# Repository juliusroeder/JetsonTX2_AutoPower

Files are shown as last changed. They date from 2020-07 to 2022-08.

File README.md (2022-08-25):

# JetsonTX2_AutoPower
Auto power on for the JetsonTX2 revision C02

One problem of the C02 revision of the Jetson TX2 dev kit is that auto power on is not easy to activate.
It includes desoldering and soldering 0402 resistors. The full process is described here: https://forums.developer.nvidia.com/t/auto-power-on-with-c02-carrier-board/70858

I needed a simpler way of automating the auto power on without the risk of damaging the TX2 by desoldering all other resistors next to R313.
Initially I tested the solution posted here: https://medium.com/@dumiloghin/auto-power-on-for-jetson-tx1-tx2-with-arduino-a5bd1b37659e
It turns on the TX2 using an Arduino Uno and is an excellent easy solution.

However, I needed a smaller form factor that could be co-hosted with the TX2 in a small steel enclosure.

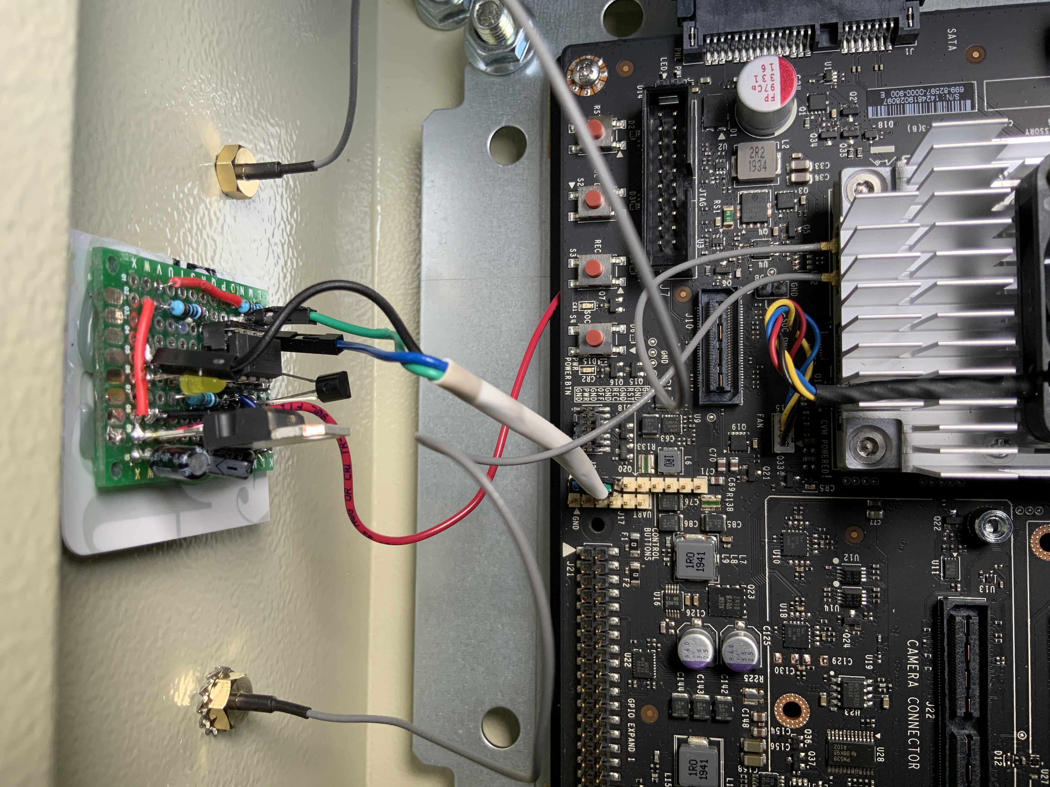
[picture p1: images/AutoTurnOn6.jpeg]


Additionally, the only power source available to drive any logic was the 20V rail on the TX2.
In this project I am using an LDO to regulate the 20V to 5V, power an ATtiny85 microcontroller and use it to turn on the TX2 via the J20 header. The microcontroller is mostly in a sleep state and draws very little power, therefore the LDO won't heat up too much.

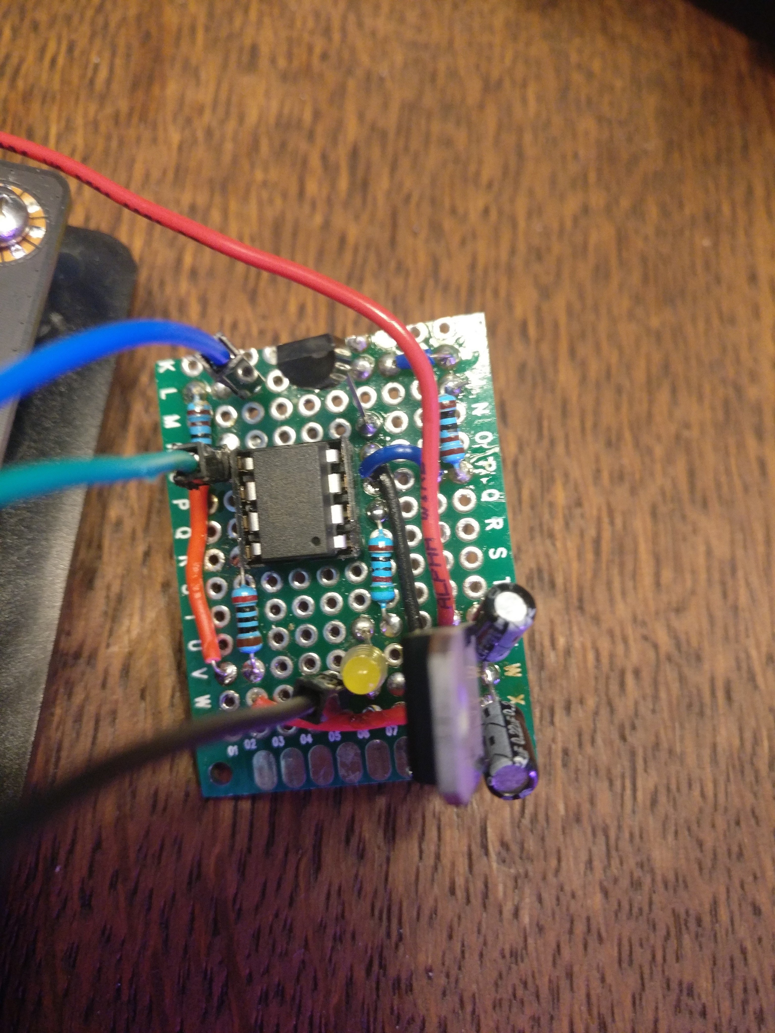
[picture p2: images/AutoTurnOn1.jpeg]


# Overview
The /src/ folder contains the very straigtforward main file for the ATtiny85.
The Tiny checks if the Jetson is on, if not it turns on the Jetson. If the Jetson is on then the Tiny goes into sleep mode.
The sleep mode is the deepest sleep mode available on the Tiny, but as we enable the interrupts before going to sleep the Tiny will wake up to turn on the Jetson again if it shuts down unexpectedly.

The command line commands for compiling and flashing the ATtiny85 are in the `compile.sh`.
Depending on your compiler please adjust the `-c` flag of `avrdude`.

The images folder contains additional images of the final "product".

An inital version of the PCB can be found in the PCB folder. It was created with KiCad.
Unfortunatly, I did not have the time to have it manufactured but made it by hand. Additionally, I am more of a software person than a hardware person. Please let me know if you find any boo-boo's.

# Requirements

To build your own circuit you will need the following material & equipment:

- avr-gcc, avr-objcopy, avrdude
- a bit of soldering knowledge & soldering iron
- a programmer for the ATtiny85. I use the one mentioned in the table below. If you use a different one don't forget to change it in the avrdude command. 
- the parts on the list below
- consumables (solder, jumper cables, heat shrink, some thicker (i.e. lower gauge) wire)

## List of material

Part description | Number | On Schematic | Datasheet link
-----------------|--------|--------------|---------------
ATtiny85 | 1 | U1 | http://ww1.microchip.com/downloads/en/DeviceDoc/Atmel-2586-AVR-8-bit-Microcontroller-ATtiny25-ATtiny45-ATtiny85_Datasheet.pdf
Programmer | 1 | na | e.g. https://www.fischl.de/ispnub/
LDO - L7805 TO-220 | 1 | U2 |  https://www.st.com/resource/en/datasheet/l78.pdf
BJT - 2N2222 | 1 | Q1 | https://www.onsemi.com/pub/Collateral/P2N2222A-D.PDF
Capacitor - 0.47μF | 1 | C1 | na
Capacitor - 0.22μF | 1 | C2 | na
Resistor - 200Ω | 1 | R1 | na
Resistor - at least 125Ω | 1 | R2 | na
Resistor - 1kΩ | 2 | R3 & R4 | na
LED | 1 | D1 | na

On the Schematic the BJT is a 2N2219, which should also work.

For R2 use something that matches your LED but use at least 125Ω as the Tiny I/O pins support a maximum of 40mA. I used between 500Ω to 1000Ω.

The capacitors I used are electrolytic, it would probably be better to use a ceramic cap for the 0.22μF.
On the other hand the capacitors are not essential and it should work without the caps, but keep in mind that the LDO datasheet does recommend them.

# Schematic

The connections on the board look as follows:

Schematic

There are four connection points to the Jetson - H1 to H4.

* H1 goes to the *PWR* pin on the J20 header this is the pin that needs to be pulled low for 1.5 to 2 seconds to turn on the Jetson.
* H2 goes to the *OFF* pin on the J20 header and is used to detect if the Jetson is on or off.
* H3 goes to the 20V rail on the Jetson.
* H4 goes to ground on the Jetson.

More details if you are not such a hardware person (which includes me):
1. H3 goes into the LDO.
2. The LDO decreases the voltage to 5V.
3. The capacitors on the input and output of the LDO are used to decrease noise.
4. The 5 volt is used to drive the ATtiny85 via pin 8 (VCC).
5. The ATtiny85 checks if the Jetson is turned on or off - via pin 5 (PB0 going to H2).
6. If the Jetson is off the ATtiny85 sets pin 3 (PB4) to high which activates the BJT and pulls H1 low. Pulling H1 low is the same as pressing the power button.
7. The Tiny is also connected to a status LED via pin 2 (PB3). The status LED either blinks (very) slowly or is on (when the Jetson is on).
7. All ground points are connected to each other and are connected to the Jetson ground via H4.

# JetsonTX2 connections

The following image shows the top view of the TX2. The J20 header is circled in yellow.
To reach the 20V rail you need to access the bottom of the board and unscrew the 4 screws circled in red.

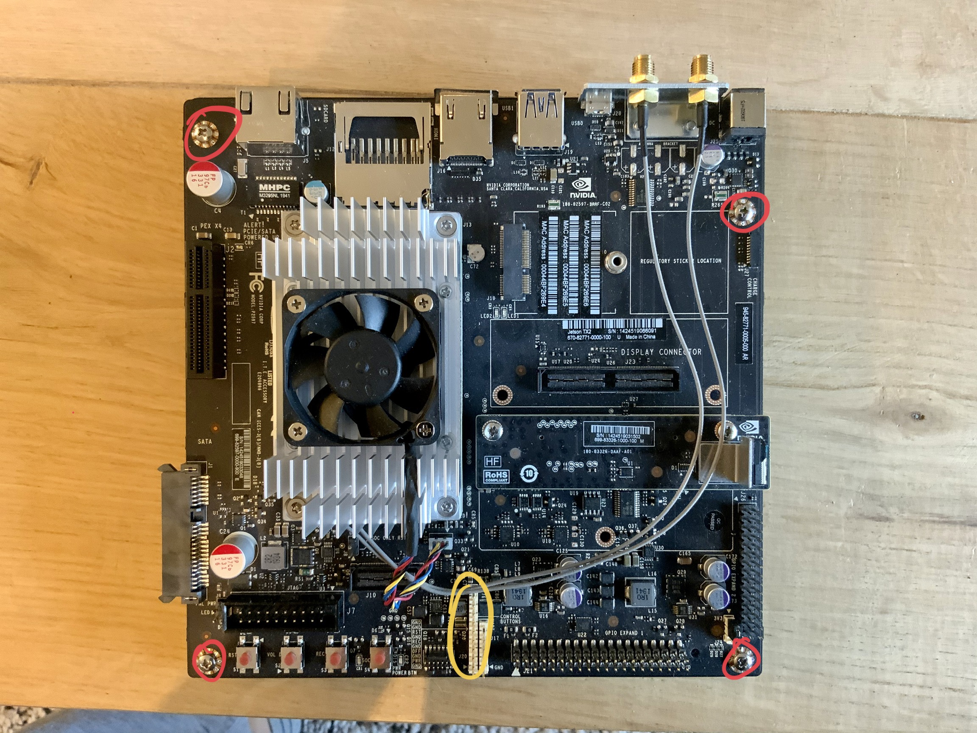
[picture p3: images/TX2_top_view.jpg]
TX2 Top View


Solder a thicker wire to the point on the PCB circled in red. The yellow circle shows the location of the wifi antenna connectors.
The thicker wire is not essential but it will withstand a bit more physical stress.

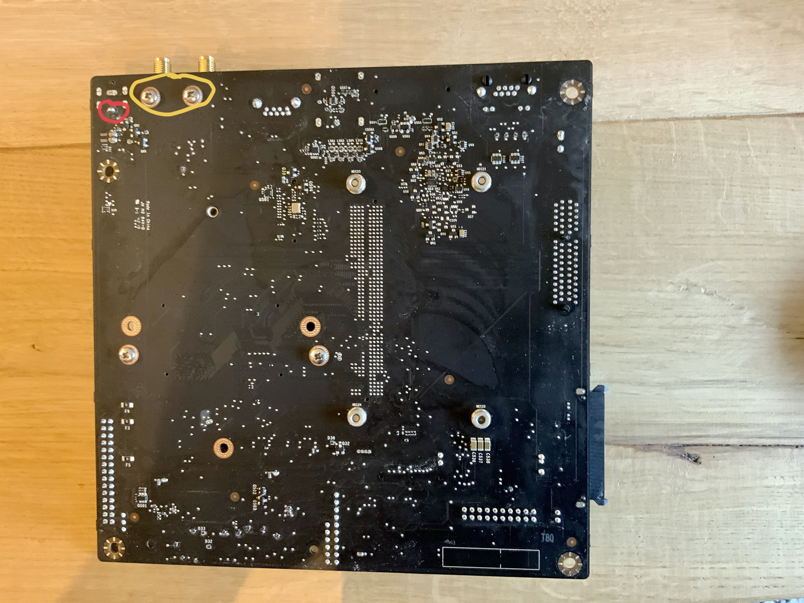
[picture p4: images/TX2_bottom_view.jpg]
TX2 Bottom View


The J20 header is shown in the next picture. The red circle shows the actual header, the yellow shows the description off the pins we actually use.
The bottom pin is the *PWR* pin, i.e. we connect this to H1.
The middle pin is the ground pin, i.e. we connect H4 here.
The top pin is the *OFF* pin, i.e. we connect H2 here.

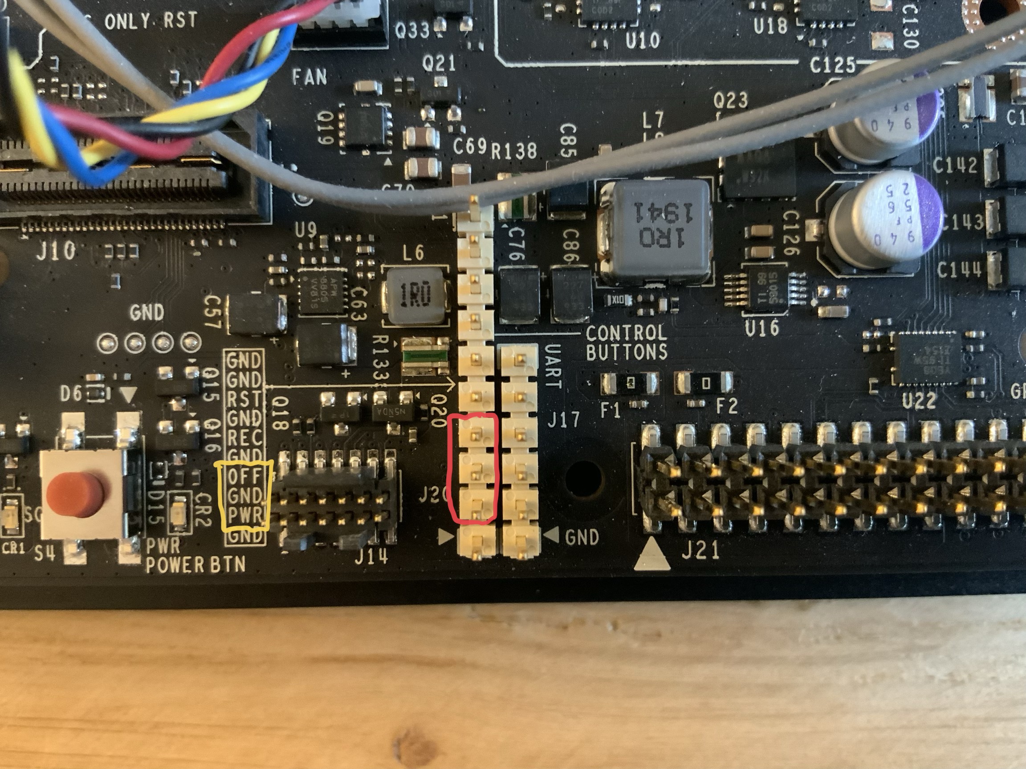
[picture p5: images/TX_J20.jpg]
TX2 Header


I built my boards in such a way that I could heat shrink the three wires going to J20 together. This adds physical stability and also makes it more unlikely for individual wires to detach from the header.

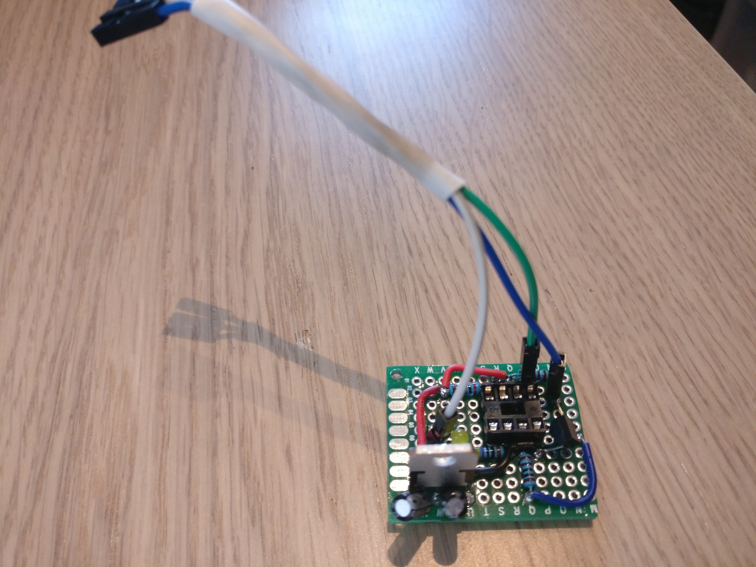
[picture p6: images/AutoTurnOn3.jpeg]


# PCB
You can find the initial version of the pcb schematics, KiCad project and gerber files in the pcb folder. I have not tried to manufacture these as I ran out of time and I needed the boards asap. So I manufactured them by hand.

I changed all components to be SMD components, with the exception of the ATtiny85.

# Possible changes
- leave out the status LED - after the Jetson is turned on this consumes the most energy

# Disclaimer

I am not responsible for any damages caused to you or your equipment, board etc. When working with electronics proceed with caution. If you do not understand what you are doing, ask for the help of a professional.
That said, please do let me know if you have any suggestions!

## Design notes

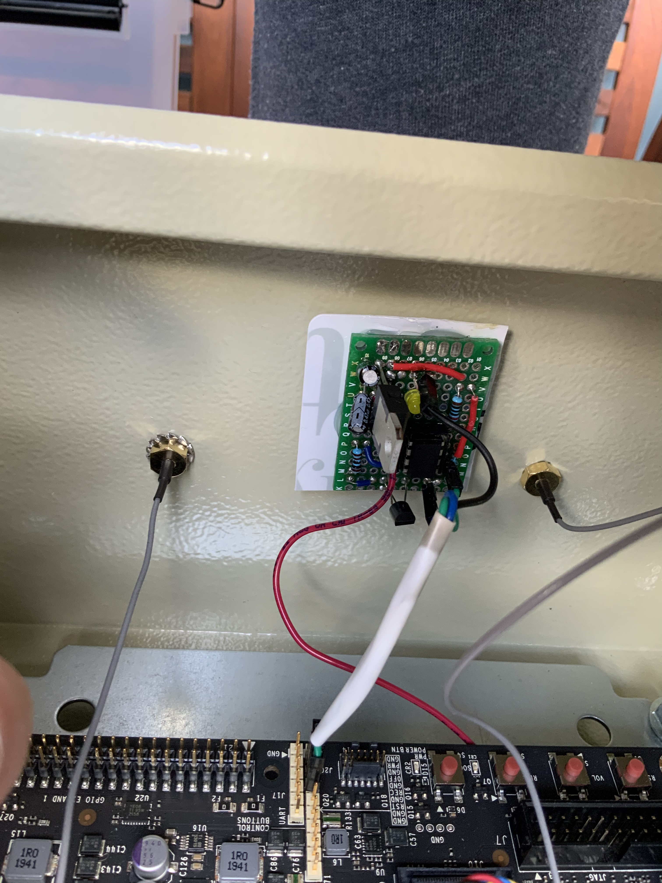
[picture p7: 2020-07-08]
images/AutoTurnOn7.jpeg

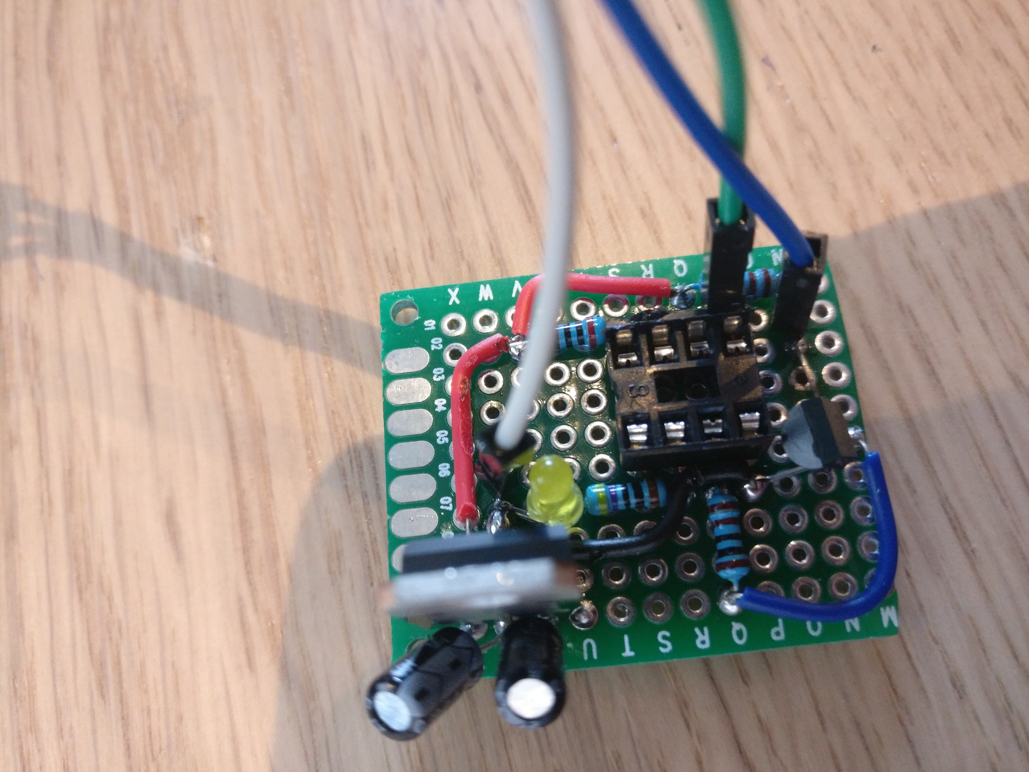
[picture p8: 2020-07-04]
images/AutoTurnOn2.jpeg

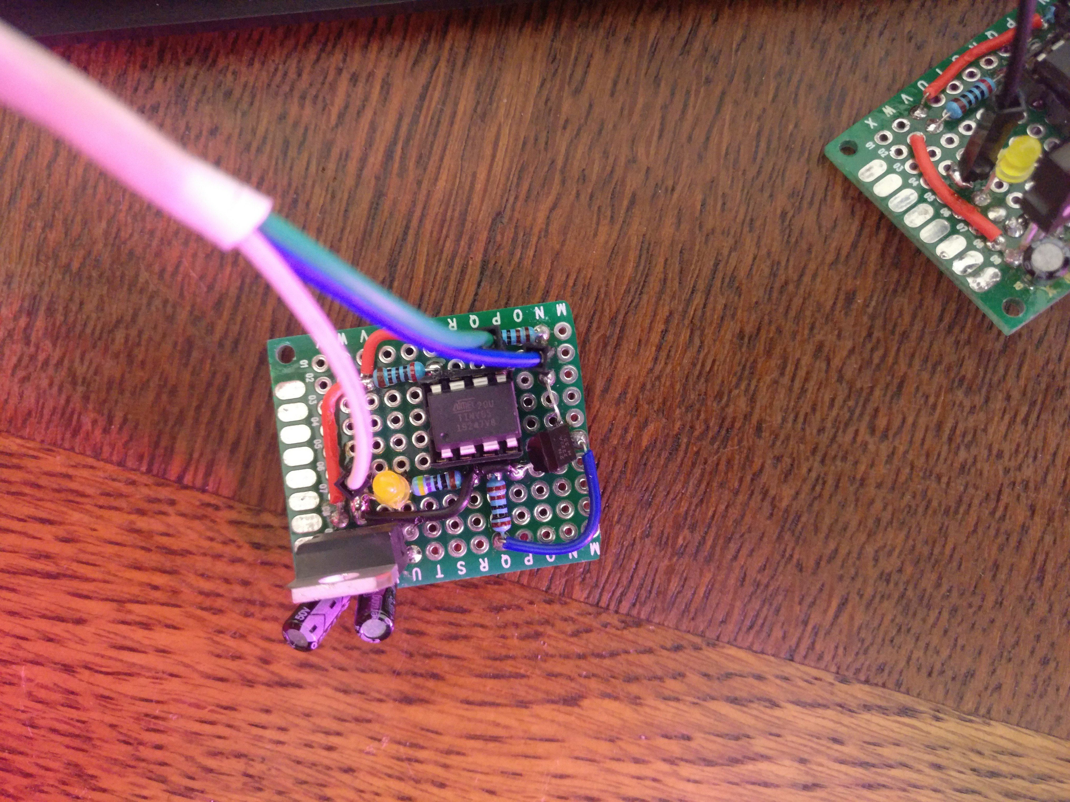
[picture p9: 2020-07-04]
images/AutoTurnOn5.jpeg

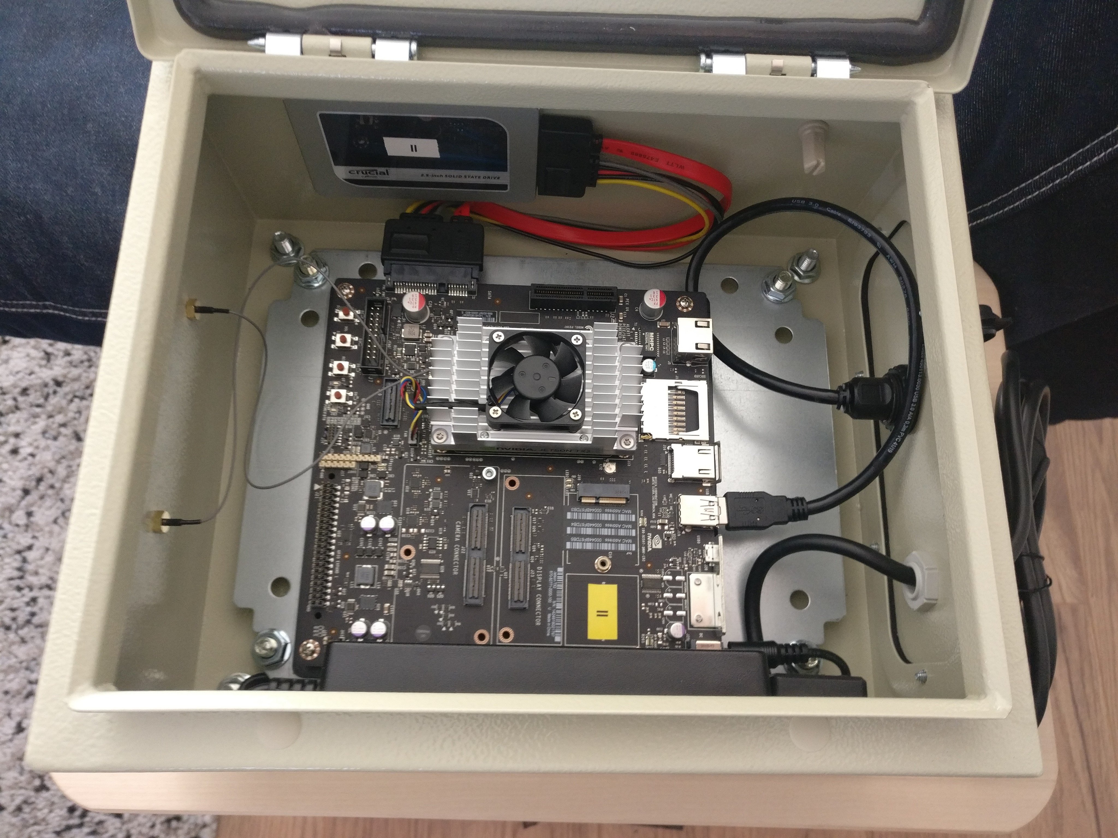
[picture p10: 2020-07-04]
images/AutoTurnOn4.jpeg

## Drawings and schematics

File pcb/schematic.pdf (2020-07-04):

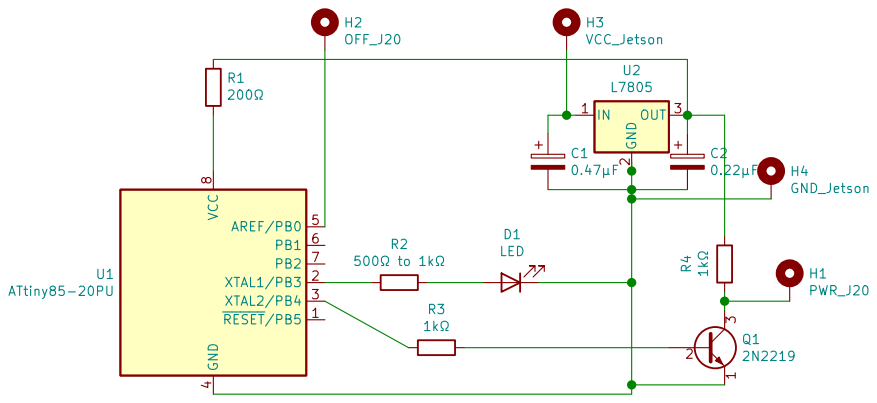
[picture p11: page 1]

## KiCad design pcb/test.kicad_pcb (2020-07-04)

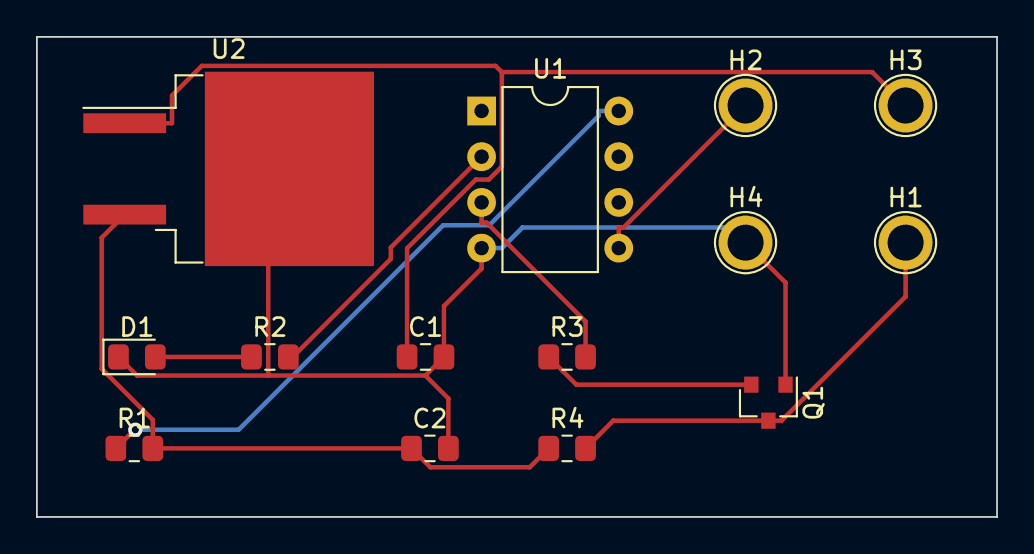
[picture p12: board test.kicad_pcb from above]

Board: 2 copper layers, 53.3 x 26.7 mm, 14 parts (0 on the bottom side), 10 nets.

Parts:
C1: 0.47uF; C_0805_2012Metric_Pad1.15x1.40mm_HandSolder
C2: 0.22uF; C_0805_2012Metric_Pad1.15x1.40mm_HandSolder
D1: LED; LED_0805_2012Metric_Pad1.15x1.40mm_HandSolder
H1: PWR_J20; TestPoint_Plated_Hole_D2.0mm
H2: OFF_J20; TestPoint_Plated_Hole_D2.0mm
H3: VCC_Jetson; TestPoint_Plated_Hole_D2.0mm
H4: GND_Jetson; TestPoint_Plated_Hole_D2.0mm
Q1: 2N2219; SOT-23
R1: 200R; R_0805_2012Metric_Pad1.15x1.40mm_HandSolder
R2: 500R; R_0805_2012Metric_Pad1.15x1.40mm_HandSolder
R3, R4: 1k; R_0805_2012Metric_Pad1.15x1.40mm_HandSolder
U1: ATtiny85-20PU; DIP-8_W7.62mm
U2: L7805; TO-263-2

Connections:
unnamed: C1.1, H3.1, U2.1
unnamed: C1.2, C2.2, D1.1, H4.1, Q1.1, U1.4, U2.2
unnamed: C2.1, R1.2, R4.1, U2.3
unnamed: D1.2, R2.1
unnamed: H1.1, Q1.3, R4.2
unnamed: H2.1, U1.5
unnamed: Q1.2, R3.1
unnamed: R1.1, U1.8
unnamed: R2.2, U1.2
unnamed: R3.2, U1.3

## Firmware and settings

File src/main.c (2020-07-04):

#include <avr/io.h>
#include <util/delay.h>
#include <avr/sleep.h>
#include <avr/interrupt.h>
#include <avr/power.h>

#define DELAY_MS 1000

void power_on(void){
    _delay_ms(DELAY_MS);
    PORTB |= _BV(PB4); // high
    _delay_ms(DELAY_MS*2); //power button has to be pushed a good amount of time
    PORTB &= ~_BV(PB4); // low
    _delay_ms(DELAY_MS);
}

void setup(void){
    //all as input with pull up resistor
    PORTB = 0xff;
    DDRB = 0x00;
    cli(); //cleans interrupts

    /* set pin 3 of PORTB for status LED*/
    PORTB &= ~_BV(PB3); //pin is low at start
    DDRB |= _BV(DDB3);

    // set pin 4 of PORTB as output to turn Jetson on via PWR pin on J20
    PORTB  &= ~_BV(PB4); // portb4 is low in the beginning and has to be pulled to LOW to turn on Jetson
    DDRB |= _BV(DDB4); // portb4 is an output pin

    // set pin 2 of PORTD as input, i.e. reads if Jetson is off via OFF pin on J20
    PORTB |= _BV(PB0); // pull-up resistor active
    DDRB &= ~_BV(DDB0); //input for jetson power LED;
    _delay_ms(DELAY_MS*2);
}

ISR(PCINT0_vect, ISR_BLOCK){}


void sleep_now(void){
    //enables interrupts
    PCMSK |= _BV(PCINT0);
    GIMSK |= _BV(PCIE);
    // PCICR |= _BV(PCIE2); //required for atmega328
    sei();
    // got to sleep
    set_sleep_mode(SLEEP_MODE_PWR_DOWN);
    sleep_enable();
    sleep_mode();
    sleep_disable();
    cli(); //disables interrupts
}


int main (void)
{
    setup();

    while(1) {
      // check if jetson is on; if yes Sleep
        if (bit_is_set(PINB, PINB0)) {
            PORTB |= _BV(PB3);
            sleep_now();
            PORTB &= ~_BV(PB3);
            _delay_ms(DELAY_MS*2);
        }else{
      // else turn on
            PORTB |= _BV(PB3); //turn led on
            power_on();
            PORTB &= ~_BV(PB3); //turn off
            _delay_ms(DELAY_MS*2);
        }
    }
}

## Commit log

2020-07-04 Working version of auto turn on with attiny85
    [test.kicad_pcb, test.sch]
2021-02-14 Remake of board. added programming header and moved to SMD only.
    [test-B_Cu.gbr, test-B_SilkS.gbr, test-Edge_Cuts.gbr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]
